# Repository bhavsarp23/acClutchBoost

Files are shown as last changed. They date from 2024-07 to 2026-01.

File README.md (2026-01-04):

# AC Clutch Boost Circuit

acClutchBoost is a KiCad hardware project designed to improve AC clutch engagement on the **8th Generation Honda Civic Si**. The project addresses a common issue where the AC clutch fails to engage reliably due to increased air gap from clutch wear, particularly at high ambient temperatures.

The repository includes the **schematic**, **PCB layout**, and **BOM** required to build the circuit.

---

## Background

Over time, wear in the AC clutch friction material increases the air gap between the clutch plate and pulley. As the gap grows, the clutch solenoid may no longer generate sufficient magnetic force to pull in the clutch, especially under adverse conditions such as high temperatures.

At elevated temperatures, clutch engagement can degrade further, potentially due to reduced magnetic permeability of the ferrous components or increased coil resistance. The result is intermittent or complete AC failure despite correct ECU commands.

---

## Concept

When the vehicle ECU commands AC clutch engagement, **acClutchBoost** briefly increases the voltage supplied to the clutch coil above the nominal automotive range (approximately 12–14 V). This higher voltage is applied for a short, configurable duration to ensure reliable pull-in of the clutch. After this initial boost period, the circuit returns the clutch supply to normal voltage to avoid overheating or long-term stress.

This approach improves engagement reliability without permanent mechanical modification of the clutch assembly.

---

## Key Features

- Interfaces directly with the factory AC clutch control signal
- Momentary voltage boost during clutch engagement
- Adjustable boost voltage
- Adjustable boost duration
- Returns to nominal voltage after engagement
- Designed specifically for 8th Gen Civic Si electrical characteristics

---

## Design Overview

The circuit consists of:

- **Non-isolated DC-DC step-up (boost) converter**
  - Trimmable output voltage
  - Raises clutch supply voltage during engagement
- **Relay-based switching**
  - Selects between nominal supply and boosted supply
  - Ensures normal operation after engagement
- **Adjustable timing circuit**
  - Controls the duration of the voltage boost
  - Allows tuning for different wear conditions or temperatures

---

## Repository Contents

- **Schematic**  
  Complete circuit design showing power, control, and timing sections.

- **PCB Layout**  
  Board layout suitable for automotive installation considerations.

- **BOM (Bill of Materials)**  
  Component list with values and part references.

---

## Adjustability

- **Boost Voltage**  
  Set via trim potentiometer on the DC-DC converter.

- **Boost Duration**  
  Controlled by the adjustable timing circuit to apply voltage only during initial engagement. Set via trim potentiometer.

Both parameters can be tuned to balance reliable clutch pull-in with long-term component safety.

---

## Intended Use

This project is intended for:
- Experimental and educational use
- Automotive electronics enthusiasts
- Situations where AC clutch wear causes unreliable engagement

It is not a replacement for proper mechanical repair, but a practical electrical mitigation for a known failure mode.

---

## Tools

- KiCad (for viewing and modifying schematic and PCB)
- Standard PCB fabrication and assembly tools

---

## Disclaimer

This project interfaces with automotive electrical systems. Improper installation or tuning may result in damage to vehicle components or injury. Use at your own risk.

---

## License

## License

This project is licensed under the **CERN Open Hardware Licence v2 – Weakly Reciprocal (CERN-OHL-W v2)**.

You are free to use, modify, manufacture, and distribute this hardware design, provided that any modifications to the licensed material are released under the same license.

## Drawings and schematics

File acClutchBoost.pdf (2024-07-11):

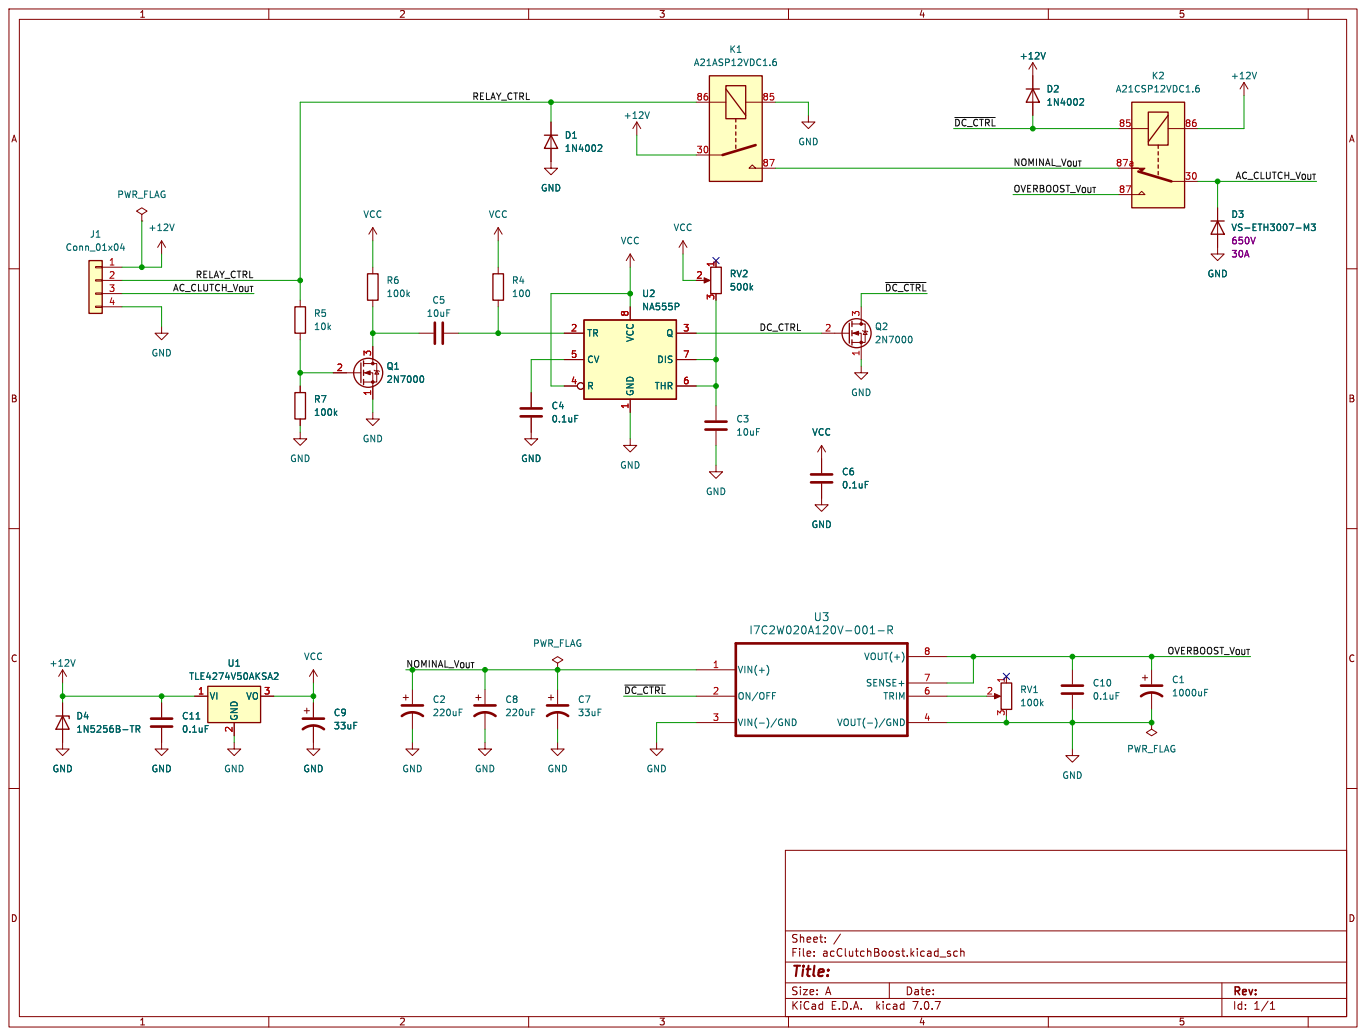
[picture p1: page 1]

Id: 1/1 Title: File: acClutchBoost.kicad_sch Sheet: /

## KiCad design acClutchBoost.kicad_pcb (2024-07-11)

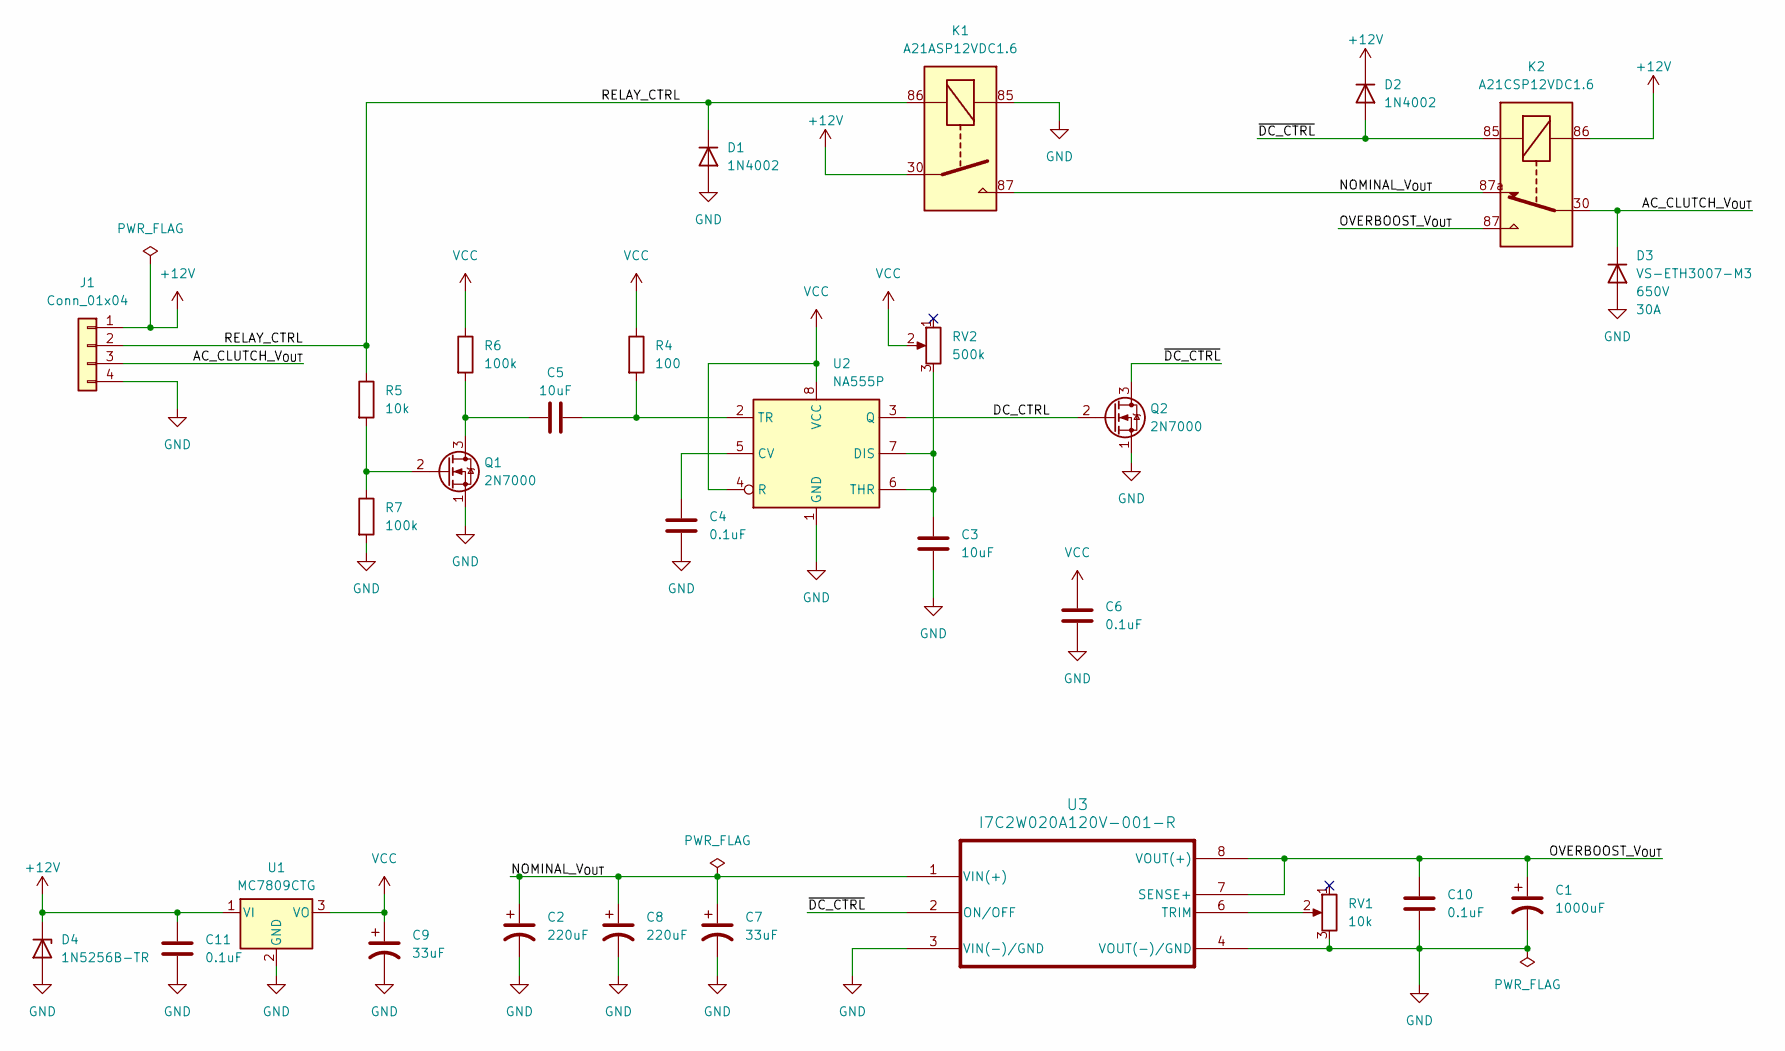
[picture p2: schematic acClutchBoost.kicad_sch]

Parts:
C1: 1000uF; CP_Radial_D12.5mm_P5.00mm; PartNumber 35ZLH1000MEFCG412.5X20
C2, C8: 220uF; CP_Radial_D10.0mm_P5.00mm; PartNumber 50ZLH220MEFC10X16
C3, C5: 10uF; C_Disc_D3.8mm_W2.6mm_P2.50mm; PartNumber C324C106K3R5TA
C4, C6, C10, C11: 0.1uF; C_Disc_D3.8mm_W2.6mm_P2.50mm; PartNumber C320C104K5R5TA
C7, C9: 33uF; CP_Radial_D5.0mm_P2.00mm; PartNumber ELE-350ELL330ME11D
D1, D2: 1N4002; D_DO-41_SOD81_P7.62mm_Horizontal; PartNumber 1N4002
D3: VS-ETH3007-M3; TO-220-2_Vertical; Voltage 650V; PartNumber VS-ETH3007-M3
D4: 1N5256B-TR; D_DO-35_SOD27_P7.62mm_Horizontal; PartNumber 1N5256B-TR
J1: Conn_01x04; SolderWire-2.5sqmm_1x04_P7.2mm_D2.4mm_OD3.6mm
K1: A21ASP12VDC1.6; AutomotiveA2Relay_Form1A; PartNumber A21ASP12VDC1.6
K2: A21CSP12VDC1.6; AutomotiveA2Relay_Form1C; PartNumber A21CSP12VDC1.6
Q1, Q2: 2N7000; TO-92_Inline; PartNumber 2N7000
R4: 100; R_Axial_DIN0204_L3.6mm_D1.6mm_P7.62mm_Horizontal
R5: 10k; R_Axial_DIN0204_L3.6mm_D1.6mm_P7.62mm_Horizontal
R6, R7: 100k; R_Axial_DIN0204_L3.6mm_D1.6mm_P7.62mm_Horizontal
RV1: 10k; Potentiometer_Bourns_3296W_Vertical; PartNumber 3296W-1-103LF
RV2: 500k; Potentiometer_Bourns_3296W_Vertical; PartNumber 3296W-1-504LF
U1: MC7809CTG; TO-220-3_Vertical; PartNumber MC7809CTG
U2: NA555P; DIP-8_W7.62mm; PartNumber NA555P
U3: I7C2W020A120V-001-R; CONV_I7C2W020A120V-001-R; PartNumber I7C2W020A120V-001-R

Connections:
+12V: C11.1, D2.1 (K), D4.1 (K), J1.1, K1.30, K2.86, U1.1 (VI)
/AC_CLUTCH_V_{OUT}: D3.1 (K), J1.3, K2.30
/DC_CTRL: Q2.2 (G), U2.3 (Q)
/NOMINAL_V_{OUT}: C2.1, C7.1, C8.1, K1.87, K2.87a, U3.1 (VIN(+))
/OVERBOOST_V_{OUT}: C1.1, C10.1, K2.87, U3.7 (SENSE+), U3.8 (VOUT(+))
/RELAY_CTRL: D1.1 (K), J1.2, K1.86, R5.1
/~DC_CTRL: D2.2 (A), K2.85, Q2.3 (D), U3.2 (ON/OFF)
GND: C1.2, C2.2, C3.2, C4.2, C6.1, C7.2, C8.2, C9.2, C10.2, C11.2, D1.2 (A), D3.2 (A), D4.2 (A), J1.4, K1.85, Q1.1 (S), Q2.1 (S), R7.2, RV1.3, U1.2 (GND), U2.1 (GND), U3.3 (VIN(-)/GND), U3.4 (VOUT(-)/GND)
unnamed: C5.1, Q1.3 (D), R6.2
unnamed: Q1.2 (G), R5.2, R7.1
unnamed: C4.1, U2.5 (CV)
unnamed: C3.1, RV2.3, U2.6 (THR), U2.7 (DIS)
unnamed: C5.2, R4.2, U2.2 (TR)
unnamed: RV1.2, U3.6 (TRIM)
VCC: C6.2, C9.1, R4.1, R6.1, RV2.2, U1.3 (VO), U2.4 (R), U2.8 (VCC)

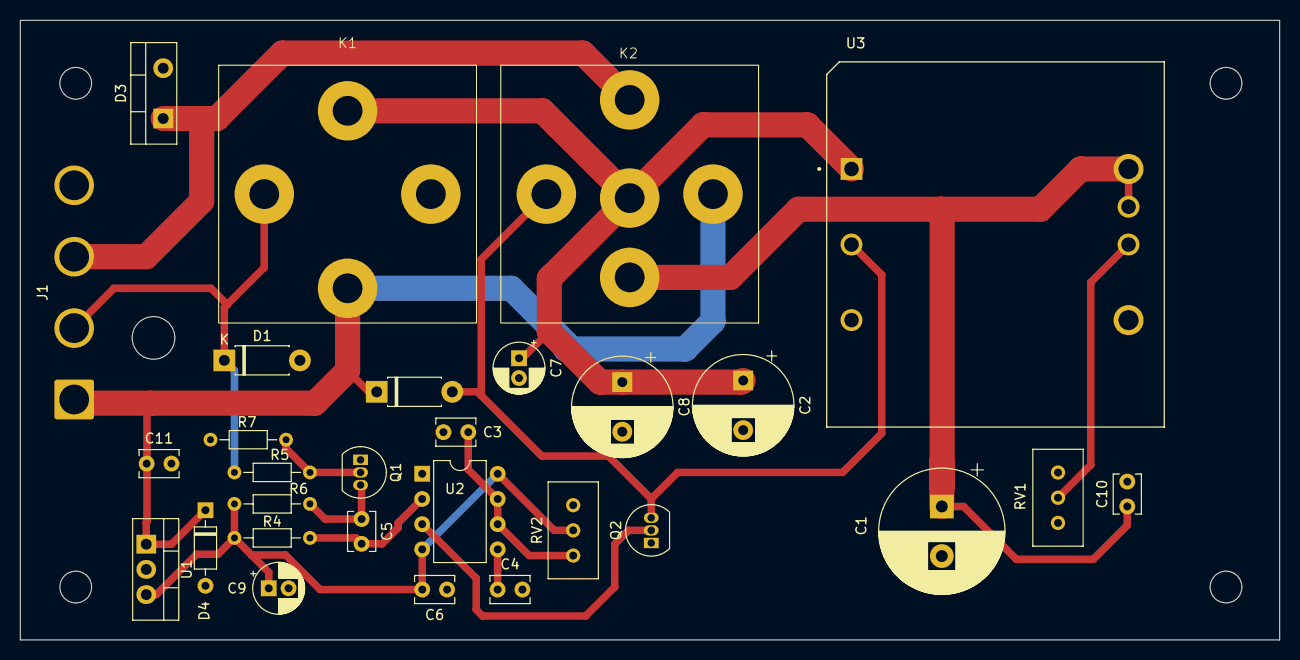
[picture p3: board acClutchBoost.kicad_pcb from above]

Board: 2 copper layers, 127.0 x 62.5 mm, 29 parts (0 on the bottom side), 15 nets.

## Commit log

2024-07-11 Add files via upload
    Initial commit
    [acClutchBoost.kicad_pcb, acClutchBoost.kicad_sch]
2026-01-04 Create README.md for AC Clutch Boost Circuit project
    Add detailed project documentation for acClutchBoost.
